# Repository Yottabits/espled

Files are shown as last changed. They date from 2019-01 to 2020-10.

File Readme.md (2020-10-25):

# ESP-LED - the ultimate LED-Strip-Controller-Board!

## What can it do?
* Controle RGB-LED strip (12V Mode)
* Controle RGBWW-LED strips (12V Mode)
* Controle WW LED-Strips (12V Mode)
* Controle WS2812 individually adressable LED Strips (5V Mode)
* Controle APA102 individually adressable LED Strips (5V Mode)
* Communicate over WiFi + MQTT
* Measure surrounding Temperature
* Sound-2-Light trough integrated Microphone

## How does it look like?
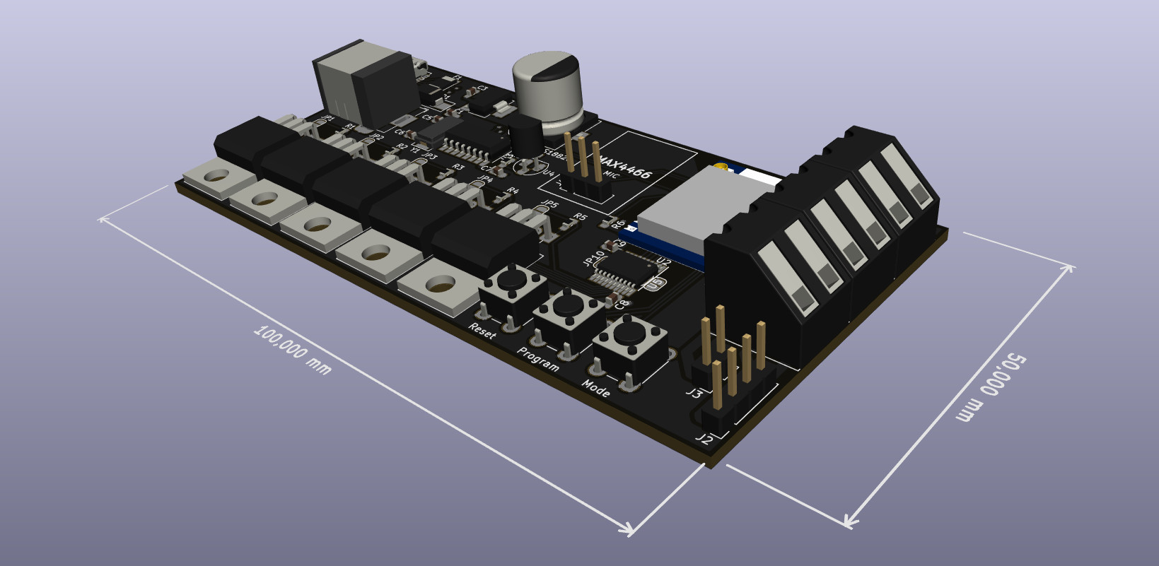
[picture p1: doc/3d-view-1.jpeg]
3D-View

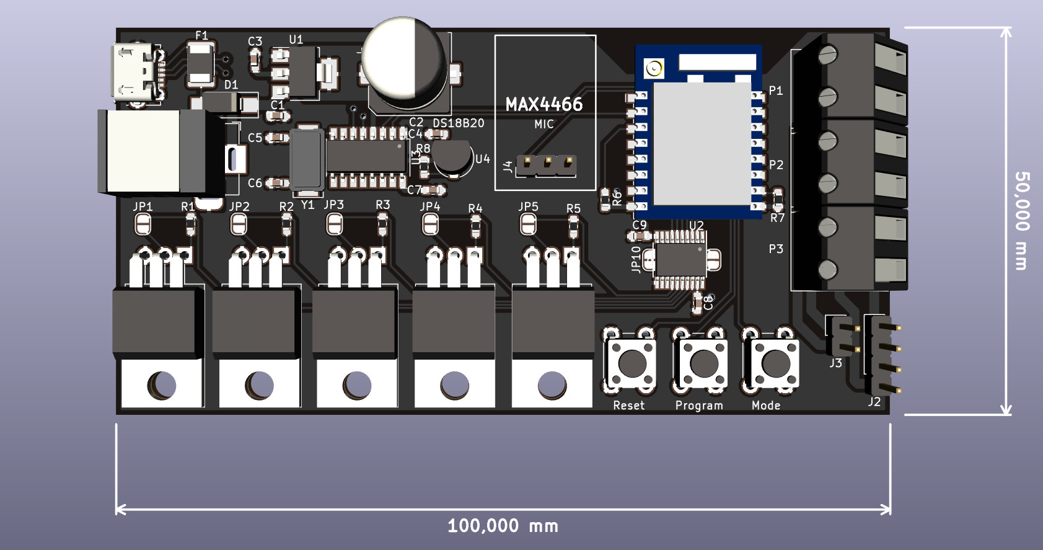
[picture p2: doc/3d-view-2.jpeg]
3D-View


## How does the Pinning look like?
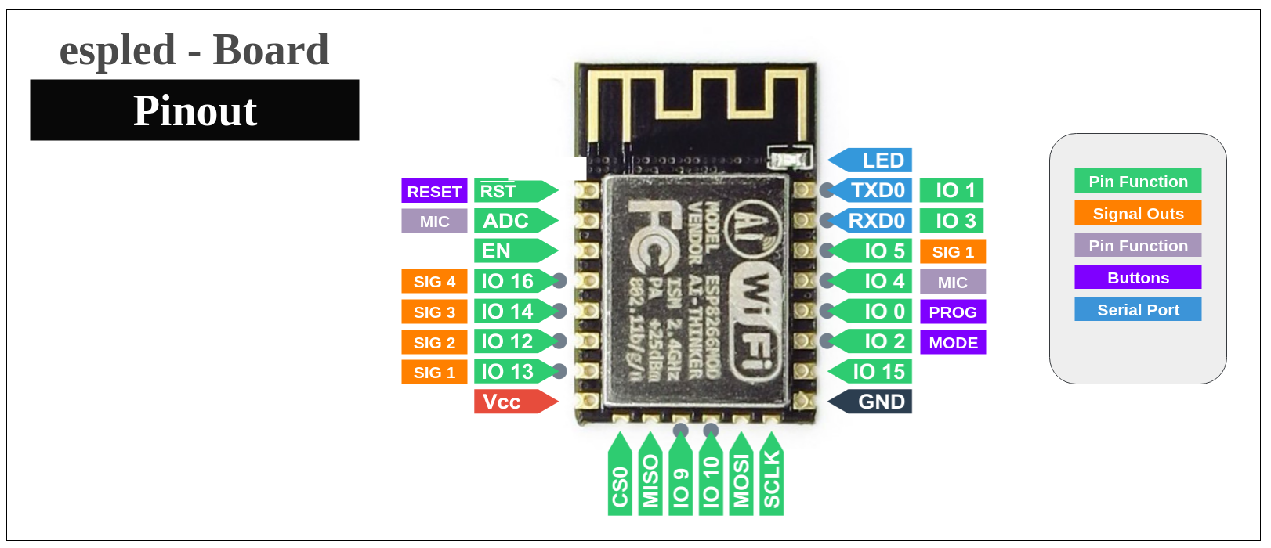
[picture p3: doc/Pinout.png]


## How to use it?

### How to use it in 12V Mode with RGBWW
Hardware:
* You only need to insert as many MOSFETS (IRLZ34N) as you want to controle Channels. Bridge the jumpers according to the table below

Software:
* Boot into configuration mode (see software README) and change the "LED Type" to "RGB", "RGBW" or "RGBWW" for 3, 4 or 5 active channels.

### How to use it in 5V Mode with WS2812
Hardware:
* Just bridge the Jumpers according to the table below.

Software:
* Boot into configuration mode (see software README) and change the "LED Type" to "WS2812".

### How to use it in 5V Mode with APA102
Hardware:
* Just bridge the Jumpers according to the table below.

Software:
* Boot into configuration mode (see software README) and change the "LED Type" to "APA102".

## What controle the Jumpers?
| Jumpernumber | Connects-Between | Function |
|---|---|---|
| 1 |Q1 Signal - Q1 Out| WS2812, APA102 |
| 2 |Q2 Signal - Q2 Out| APA102 |
| 3 |Q3 Signal - Q3 Out| |
| 4 |Q4 Signal - Q4 Out| |
| 5 |Q5 Signal - Q5 Out| |
| 6 | IO13 - Q1 | RGB, RGBW, RGBWW |
| 7 | IO12 - Q2 | RGB, RGBW, RGBWW |
| 8 | IO14 - Q3 | RGB, RGBW, RGBWW |
| 9 | IO16 - Q4 | RGBW, RGBWW |
| 10 | IO5 - Q5 | RGBWW |

## Which parts do I need?
See the Bill-Of-Materials file named ESPLED.csv in the hardware folder.

## Supported Modes
See Wiki (https://github.com/Yottabits/espled/wiki/Modes-Description)

## nice Projects with led animations for insperation
* GoodListOfAnimations for individually addressable strips: https://www.tweaking4all.com/hardware/arduino/arduino-all-ledstrip-effects-in-one/
* https://github.com/Aircoookie/WLED/wiki

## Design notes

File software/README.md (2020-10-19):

# Software manual
## Introduction

Although the ESPLED board is fully customizable, the default software should satisfy most users.

## Booting procedure
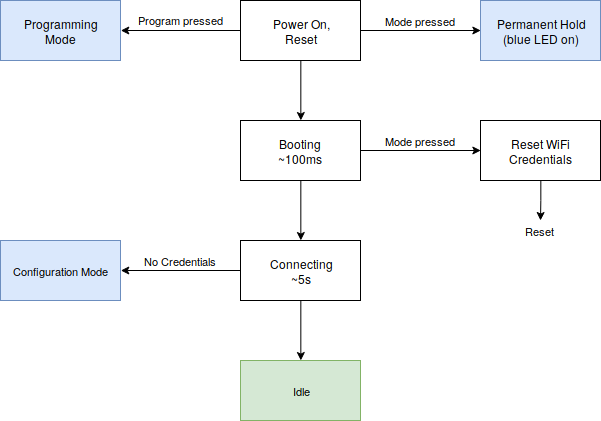
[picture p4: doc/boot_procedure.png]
boot


## Configuration
The configuration mode allows you to select your local WiFi network and the type of led strip you want to use.

To enter the configuration mode, perform the following tasks:
- Press and release the __reset__ button
- Press and hold the __mode__ button, the ESP Module should turn on its blue led permanently
- Hold the __mode__ button down until the led strip blinks blue once
- then the board is reset and should open up it's own wifi again

After sucessfully entering the configuration mode, use your smartphone or computer to connect to the wireless network called "ESPLED config" and follow the screen.

## Control LEDs
There are three different interfaces to connect to the controller.
*MQTT
*REST API
*On-Board-Button

### MQTT
The different functions of the controller are available under the following MQTT topic:

*/ESPLED/FF:FF:FF:FF:FF:FF* 
(replace with MAC of your device, visible in the setup routine)

The payload contais json in the following format:

```
{
  "mode": 0,
  "color": [
    1023,
    255,
    255,
    255,
    255
  ],
  "time": 1000
}
```

| Function | Topic | Values |
|---|---|---|
| Change Mode | mode | 0 to 200 |
| Color amplitudes | color[ R,G,B,(CW),(WW) ] | 10 bit integer |
| Timeframe in milliseconds(ex. fade time) | time | unsigned integer |
| Frequency in hertz | frequency | float |
| Relativ sensitivity | sensitivity | float (0.0 to 1.0) |
| Number of leds (mode specific) | length | unsigned integer |
| Select start led (mode specific) | position | unsigned integer |

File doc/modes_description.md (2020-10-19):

# Modes an mqtt 

## 0 fade2Color

### Description:
This is the most basic mode to change the strips color. You send the color a transition time. A transition time of 0 leads to an instant color jump.

### Parameters:
| Parameter | Effect | Unit | min. | man. |
|---|---|---|---|---|
| mode | changes Mode |  int |  0 |  0 |
| color | defines color in an Red-Green-Blue-WarmWhite-ColdWhite array | PWM  | 0 | 1023 |
| time | time until the end color is reached | milliseconds | 0 | 4294967295 ~ 49.7d |

### Example JSON:
``` JSON
{
  "mode":0,
  "color":[
      1023,
      1023,
      1023,
      1023,
      1023
  ],
  "time":1000
}
```

## 1 blinkColor

### Description:
This mode should be used for notifictaion. The Controller will store it's current state and blink in the selected color. You may select a number of blinks with the length parameter. 

### Parameters:
| Parameter | Effect | Unit | min. | man. |
|---|---|---|---|---|
| mode | changes Mode |  int |  1 |  1 |
| color | defines color in an Red-Green-Blue-WarmWhite-ColdWhite array | PWM  | 0 | 1023 |
| duration | duration of each max and min period | milliseconds | 0 | 4294967295 ~ 49.7d |
| length | number of blinks | int | 0 | ? |
| time | fadeTime from 0 to 1023| 0 | 4294967295 ~ 49.7d |

### Example JSON:
``` JSON
{
  "mode":1,
  "color":[
      1023,
      0,
      0,
      0,
      0
  ],
  "time":2000,
  "legth":3,
  "duration":1000
}
```

## 2 strobe
### Description:
This mode lights up the strip in the selected color and blinks it on/off in the selected frequency - no fading.

### Parameters:
| Parameter | Effect | Unit | min. | man. |
|---|---|---|---|---|
| mode | changes Mode |  t |  2 |  2 |
| color | defines color in an Red-Green-Blue-WarmWhite-ColdWhite array | PWM  | 0 | 1023 |
| frequency | changes the strobe frequency |  Hz |  1 |  60 |

### Example JSON:
``` JSON
{
  "mode":2,
  "color":[
      800,
      120,
      1023,
      0,
      0
  ],
  "frequency":20
}
```

## 3 sound2Light

## 4 breathe
### Description:
This mode realizes a breathing function. This means the whole strip gets dimmed up and down. You can add some randomness to that through timeVariance and maxBrightnessVariance.

### Parameters:
| Parameter | Effect | Unit | min. | man. |
|---|---|---|---|---|
| mode | changes Mode |  t |  4 |  4 |
| color | defines color in an Red-Green-Blue-WarmWhite-ColdWhite array | PWM  | 0 | 1023 |
| time | Period of whole "breath" (effected by time Variance) | milliseconds | 0 | 4294967295 ~ 49.7d |
| minBrightnes | minimum Brightness | PWM | 0 | 1023 |
| maxBrightnes | maximum Brightness (effected by maxBrightnesVariance) | PWM | 0 | 1023 |
| timeVariance | if set each breath a random amount of ms within the Interval [-timeVariance <> +timeVariance] gets added to the breath time| millisceonds | 0 | 4294967295 ~ 49.7d  |
| maxBrightnesVariance | if set each breath a random amount of brightnes within the Interval [-maxBrightnesVariance <> +maxBrightnesVariance] gets added to maxBrightnes| PWM | 0 | 1023 |

### Example JSON:
``` JSON
{
  "mode":4,
  "color":[
      1023,
      0,
      0,
      0,
      0
  ],
  "time":6000,
  "minBrightnes":0,
  "maxBrightnes":1023,
  "timeVariance":3000,
  "maxBrightnesVariance":500
}
```

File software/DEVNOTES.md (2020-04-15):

# Software development notes and ideas
## User Interface
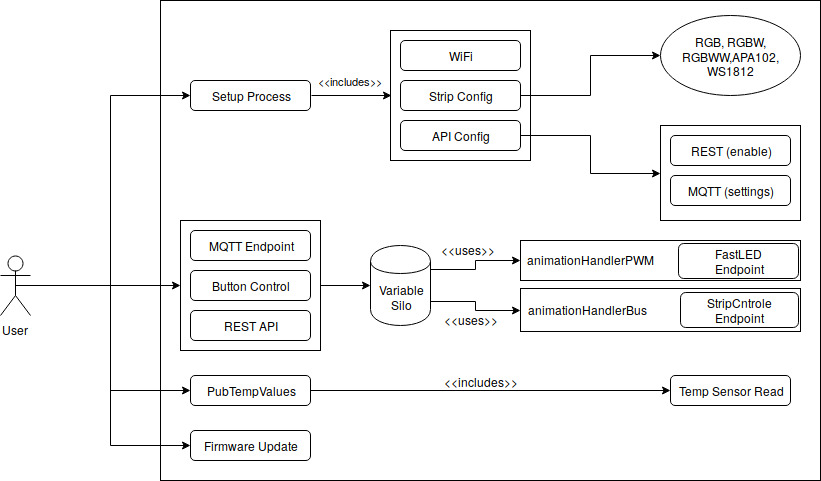
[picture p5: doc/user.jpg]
User Interface


## Class __StripControle__
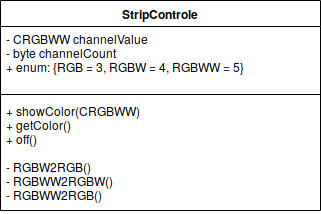
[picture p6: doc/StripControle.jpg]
StripControle


## Solution to the double class problem
```cpp
//Setup
FastLed* fastLed;
StripControle* stripControle;

//Init
if(ledChipsetBased)
{
  fastLed = new FastLed(ledArray);
}
else
{
  stripControle = new StripControle;
}
```

## AnnimationHandlers
* Both Classes AnimationHandlerPWM and AnimationHandlerBus have a method handle that is periodically called
* This handler then periodically calls functions defining the modes (distinct for bus and non Bus Stips)
* Example: animationHandlerBus.fade(Color,time)
* All current state Informations for timing-sensitive Modes is stored as static variables within their periodically called functions
* For Timing-Measurements we use the millis-command
* For Accessing the LEDs both AnimationHandlers hold attributes of the Type FastLedEndpoint and StripControleEndpoint which do the lower Level Stuff
* All Modes implemented in the AnimationHandlerPWM should also be Implemented in the AnimationHandlerBus

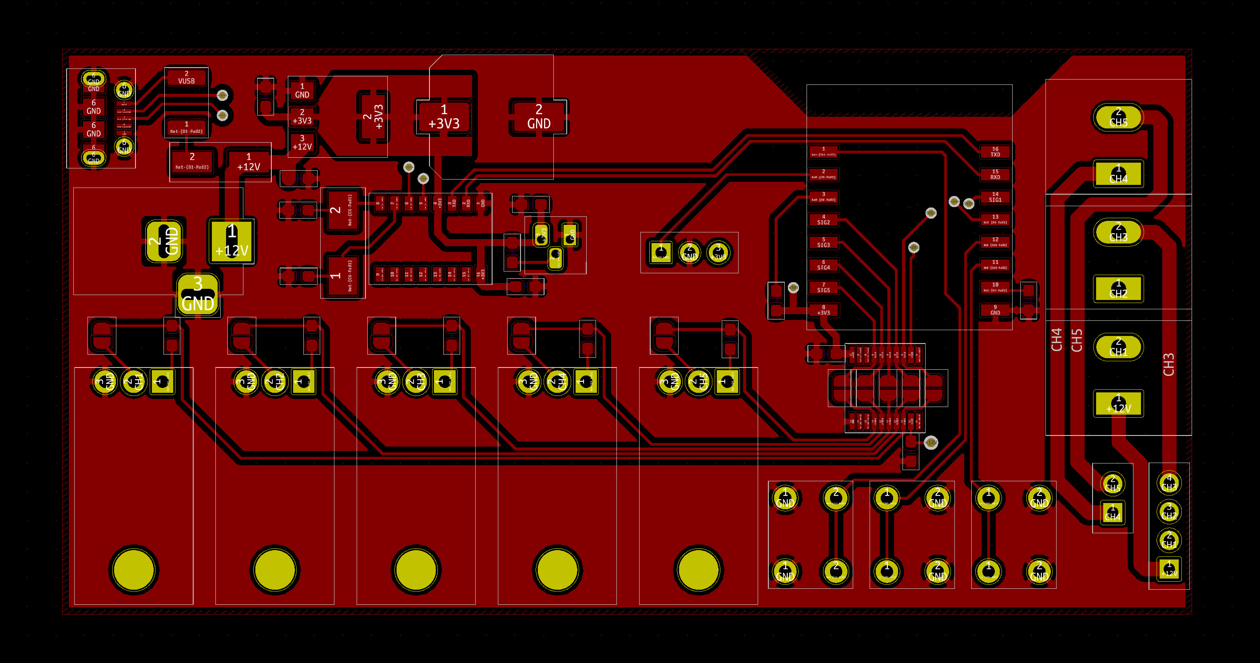
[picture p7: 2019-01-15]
doc/top_layer.jpg

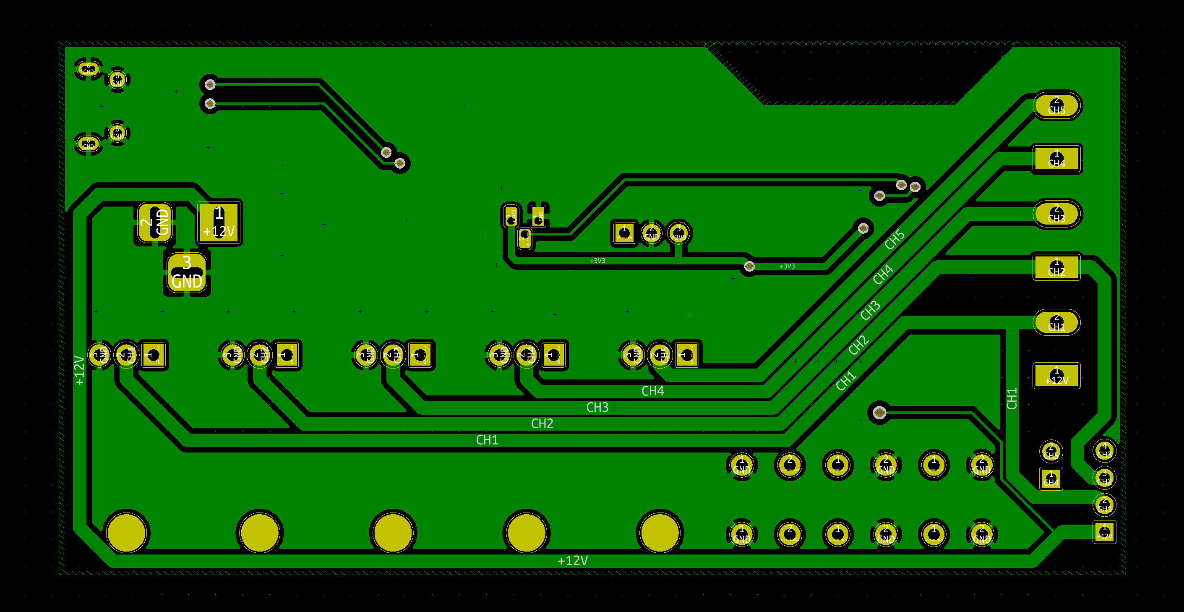
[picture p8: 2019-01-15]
doc/bottom_layer.jpg

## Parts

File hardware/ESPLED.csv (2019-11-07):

Reference | Value | Footprint | Datasheet | SKU | MPN
U2 | ESP-07v2 | RF_Module:ESP-07
C2 | 1000uF | Capacitor_SMD:CP_Elec_10x10.5
C3 | 1uF | Capacitor_SMD:C_0603_1608Metric_Pad1.05x0.95mm_HandSolder
CON1 | BARREL_JACK | Connector_BarrelJack:BarrelJack_Horizontal
Q1 | IRLZ34N | Package_TO_SOT_THT:TO-220-3_Horizontal_TabDown
Q2 | IRLZ34N | Package_TO_SOT_THT:TO-220-3_Horizontal_TabDown
Q3 | IRLZ34N | Package_TO_SOT_THT:TO-220-3_Horizontal_TabDown
R1 | 100 | Resistor_SMD:R_0603_1608Metric_Pad1.05x0.95mm_HandSolder
R2 | 100 | Resistor_SMD:R_0603_1608Metric_Pad1.05x0.95mm_HandSolder
R3 | 100 | Resistor_SMD:R_0603_1608Metric_Pad1.05x0.95mm_HandSolder
R6 | 10k | Resistor_SMD:R_0603_1608Metric_Pad1.05x0.95mm_HandSolder
R7 | 10k | Resistor_SMD:R_0603_1608Metric_Pad1.05x0.95mm_HandSolder
SW1 | Reset | Button_Switch_THT:SW_PUSH_6mm
P3 | LED_CON_SCREW | TerminalBlock:TerminalBlock_Altech_AK300-2_P5.00mm |  | 320110028
P1 | LED_CON_SCREW | TerminalBlock:TerminalBlock_Altech_AK300-2_P5.00mm |  | 320110028
C4 | 100nF | Capacitor_SMD:C_0603_1608Metric_Pad1.05x0.95mm_HandSolder
U3 | INTERFACE-CH340G | Package_SO:SOP-16_4.4x10.4mm_P1.27mm |  | 310070026 | CH340T
J1 | USB_B_Micro | Connector_USB:USB_Micro-B_Molex-105017-0001
Y1 | Crystal | Crystal:Crystal_SMD_0603-2Pin_6.0x3.5mm_HandSoldering
SW3 | Mode | Button_Switch_THT:SW_PUSH_6mm
C5 | 22p | Capacitor_SMD:C_0603_1608Metric_Pad1.05x0.95mm_HandSolder
C6 | 22p | Capacitor_SMD:C_0603_1608Metric_Pad1.05x0.95mm_HandSolder
C7 | 100n | Capacitor_SMD:C_0603_1608Metric_Pad1.05x0.95mm_HandSolder
D1 | 1N5817 | Diode_SMD:D_SMA_Handsoldering
J4 | MIC | Connector_PinHeader_2.54mm:PinHeader_1x03_P2.54mm_Vertical
J2 | LED_CON_RGB | Connector_PinHeader_2.54mm:PinHeader_1x04_P2.54mm_Vertical
Q4 | IRLZ34N | Package_TO_SOT_THT:TO-220-3_Horizontal_TabDown
R4 | 100 | Resistor_SMD:R_0603_1608Metric_Pad1.05x0.95mm_HandSolder
Q5 | IRLZ34N | Package_TO_SOT_THT:TO-220-3_Horizontal_TabDown
R5 | 100 | Resistor_SMD:R_0603_1608Metric_Pad1.05x0.95mm_HandSolder
P2 | LED_CON_SCREW | TerminalBlock:TerminalBlock_Altech_AK300-2_P5.00mm |  | 320110028
U1 | AMS1117-3.3 | Package_TO_SOT_SMD:SOT-223-3_TabPin2
F1 | Polyfuse | Fuse:Fuse_1812_4532Metric_Pad1.30x3.40mm_HandSolder
JP1 | GPIO LINK | Jumper:SolderJumper-2_P1.3mm_Open_RoundedPad1.0x1.5mm
JP2 | GPIO LINK | Jumper:SolderJumper-2_P1.3mm_Open_RoundedPad1.0x1.5mm
JP3 | GPIO LINK | Jumper:SolderJumper-2_P1.3mm_Open_RoundedPad1.0x1.5mm
JP4 | GPIO LINK | Jumper:SolderJumper-2_P1.3mm_Open_RoundedPad1.0x1.5mm
JP5 | GPIO LINK | Jumper:SolderJumper-2_P1.3mm_Open_RoundedPad1.0x1.5mm
U4 | DS18B20 | Package_TO_SOT_THT:TO-92_HandSolder
R8 | 4.7K | Resistor_SMD:R_0603_1608Metric_Pad1.05x0.95mm_HandSolder
SW2 | Program | Button_Switch_THT:SW_PUSH_6mm
C1 | 1uF | Capacitor_SMD:C_0603_1608Metric_Pad1.05x0.95mm_HandSolder
J3 | LED_CON_WW | Connector_PinHeader_2.54mm:PinHeader_1x02_P2.54mm_Vertical | ~
U5 | TXS0108EPW | Package_SO:TSSOP-20_4.4x6.5mm_P0.65mm | www.ti.com/lit/ds/symlink/txs0108e.pdf
JP6 | GPIO LINK | Jumper:SolderJumper-2_P1.3mm_Open_RoundedPad1.0x1.5mm | ~
JP7 | GPIO LINK | Jumper:SolderJumper-2_P1.3mm_Open_RoundedPad1.0x1.5mm | ~
JP8 | GPIO LINK | Jumper:SolderJumper-2_P1.3mm_Open_RoundedPad1.0x1.5mm | ~
JP9 | GPIO LINK | Jumper:SolderJumper-2_P1.3mm_Open_RoundedPad1.0x1.5mm | ~
JP10 | GPIO LINK | Jumper:SolderJumper-2_P1.3mm_Open_RoundedPad1.0x1.5mm | ~
C9 | 100nF | Capacitor_SMD:C_0603_1608Metric_Pad1.05x0.95mm_HandSolder | ~
C8 | 100nF | Capacitor_SMD:C_0603_1608Metric_Pad1.05x0.95mm_HandSolder | ~

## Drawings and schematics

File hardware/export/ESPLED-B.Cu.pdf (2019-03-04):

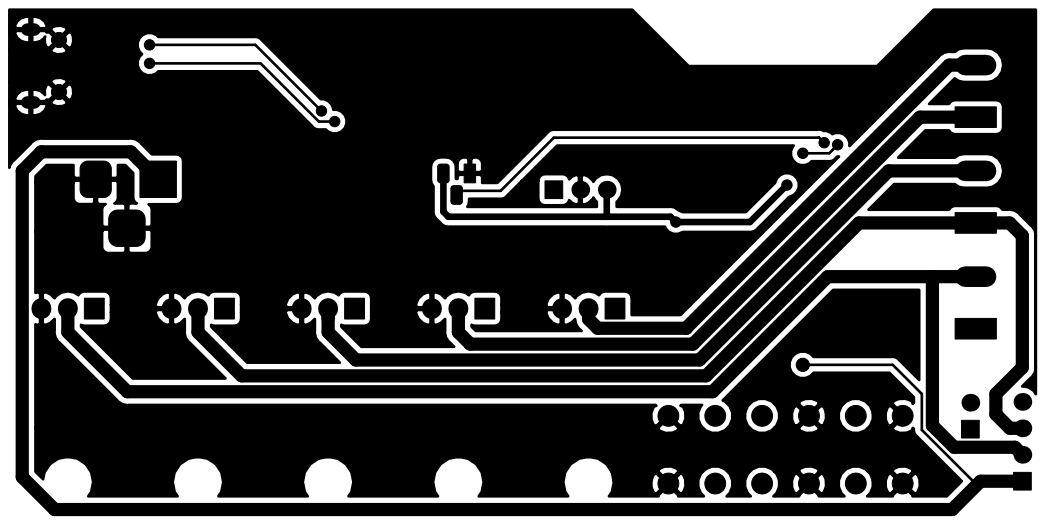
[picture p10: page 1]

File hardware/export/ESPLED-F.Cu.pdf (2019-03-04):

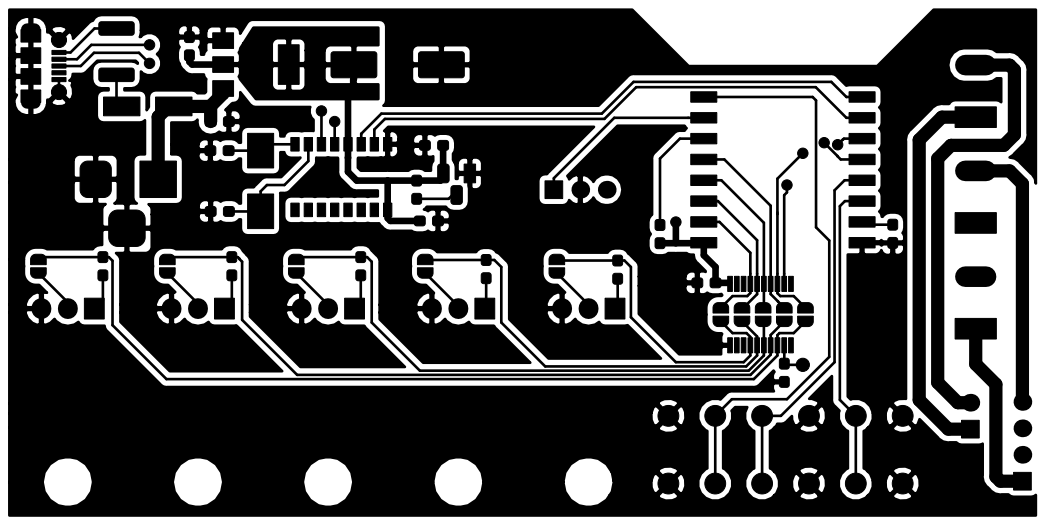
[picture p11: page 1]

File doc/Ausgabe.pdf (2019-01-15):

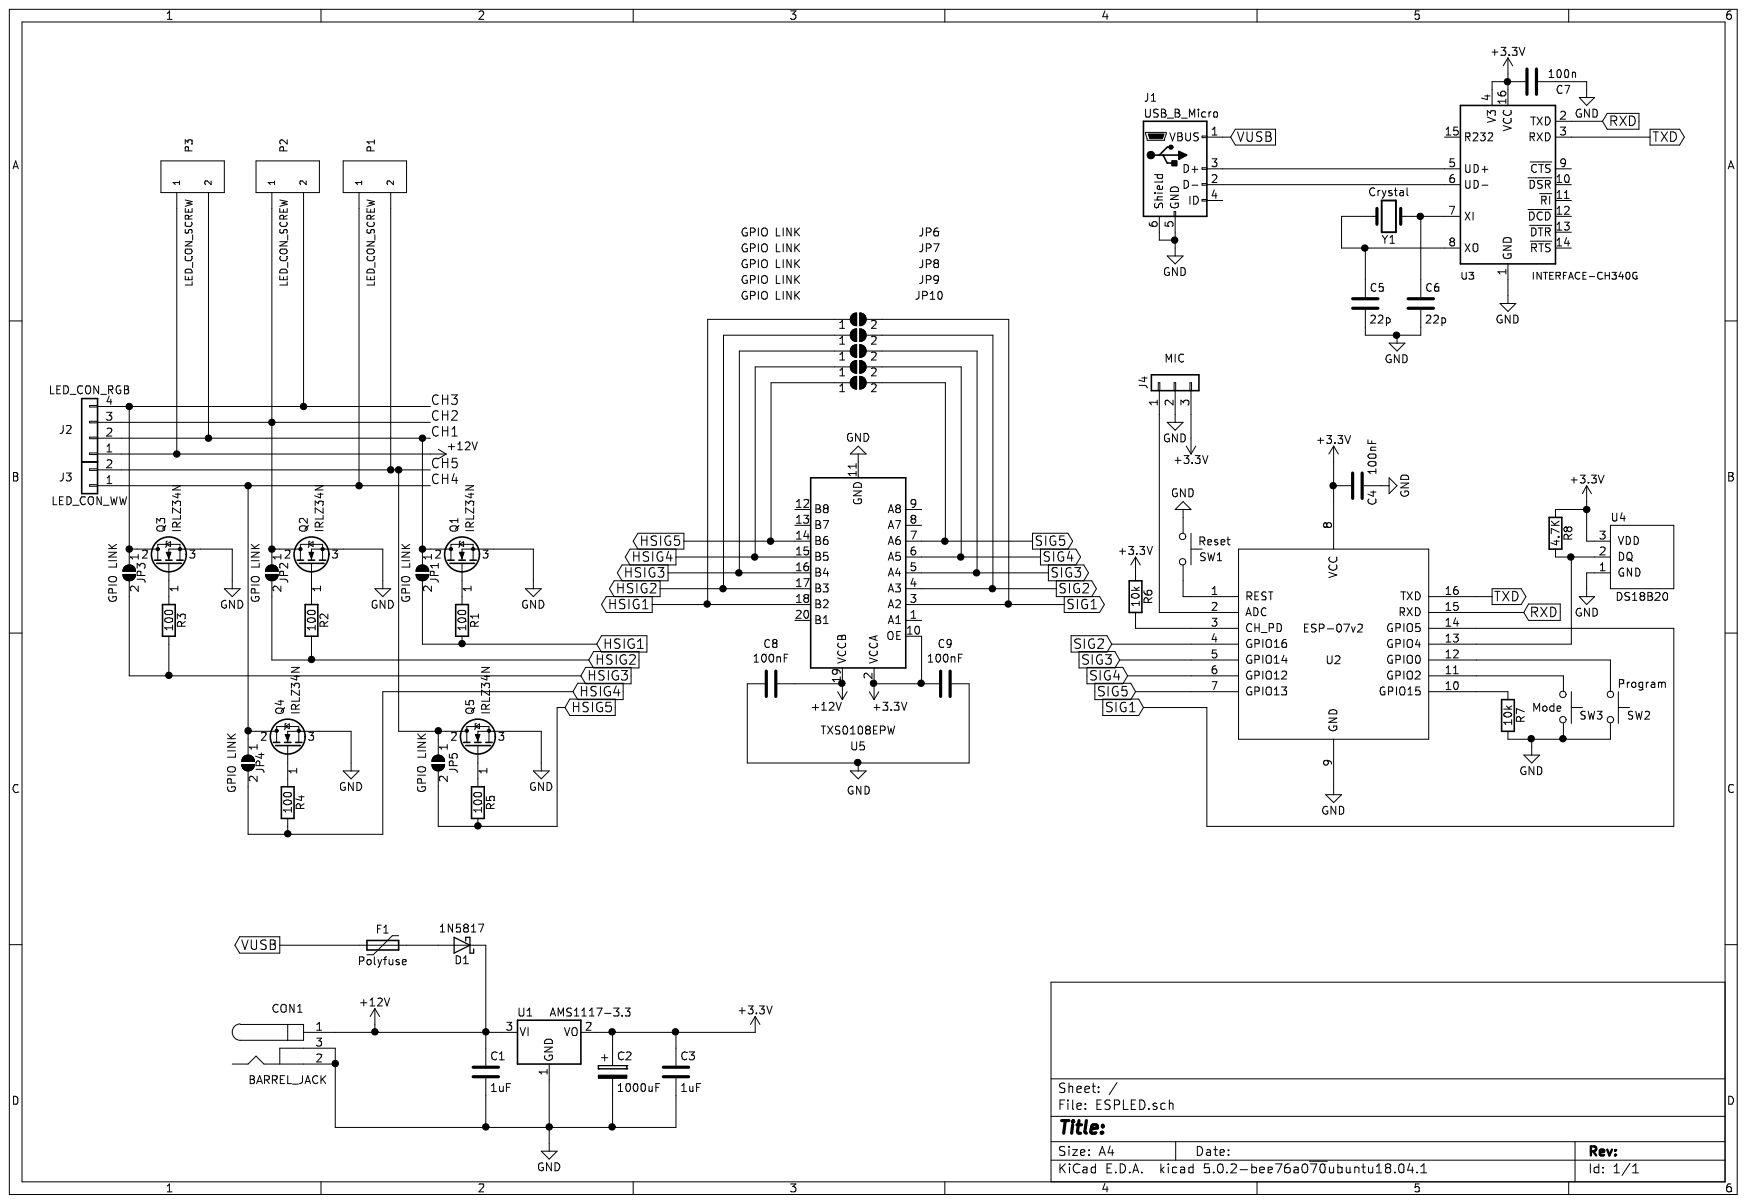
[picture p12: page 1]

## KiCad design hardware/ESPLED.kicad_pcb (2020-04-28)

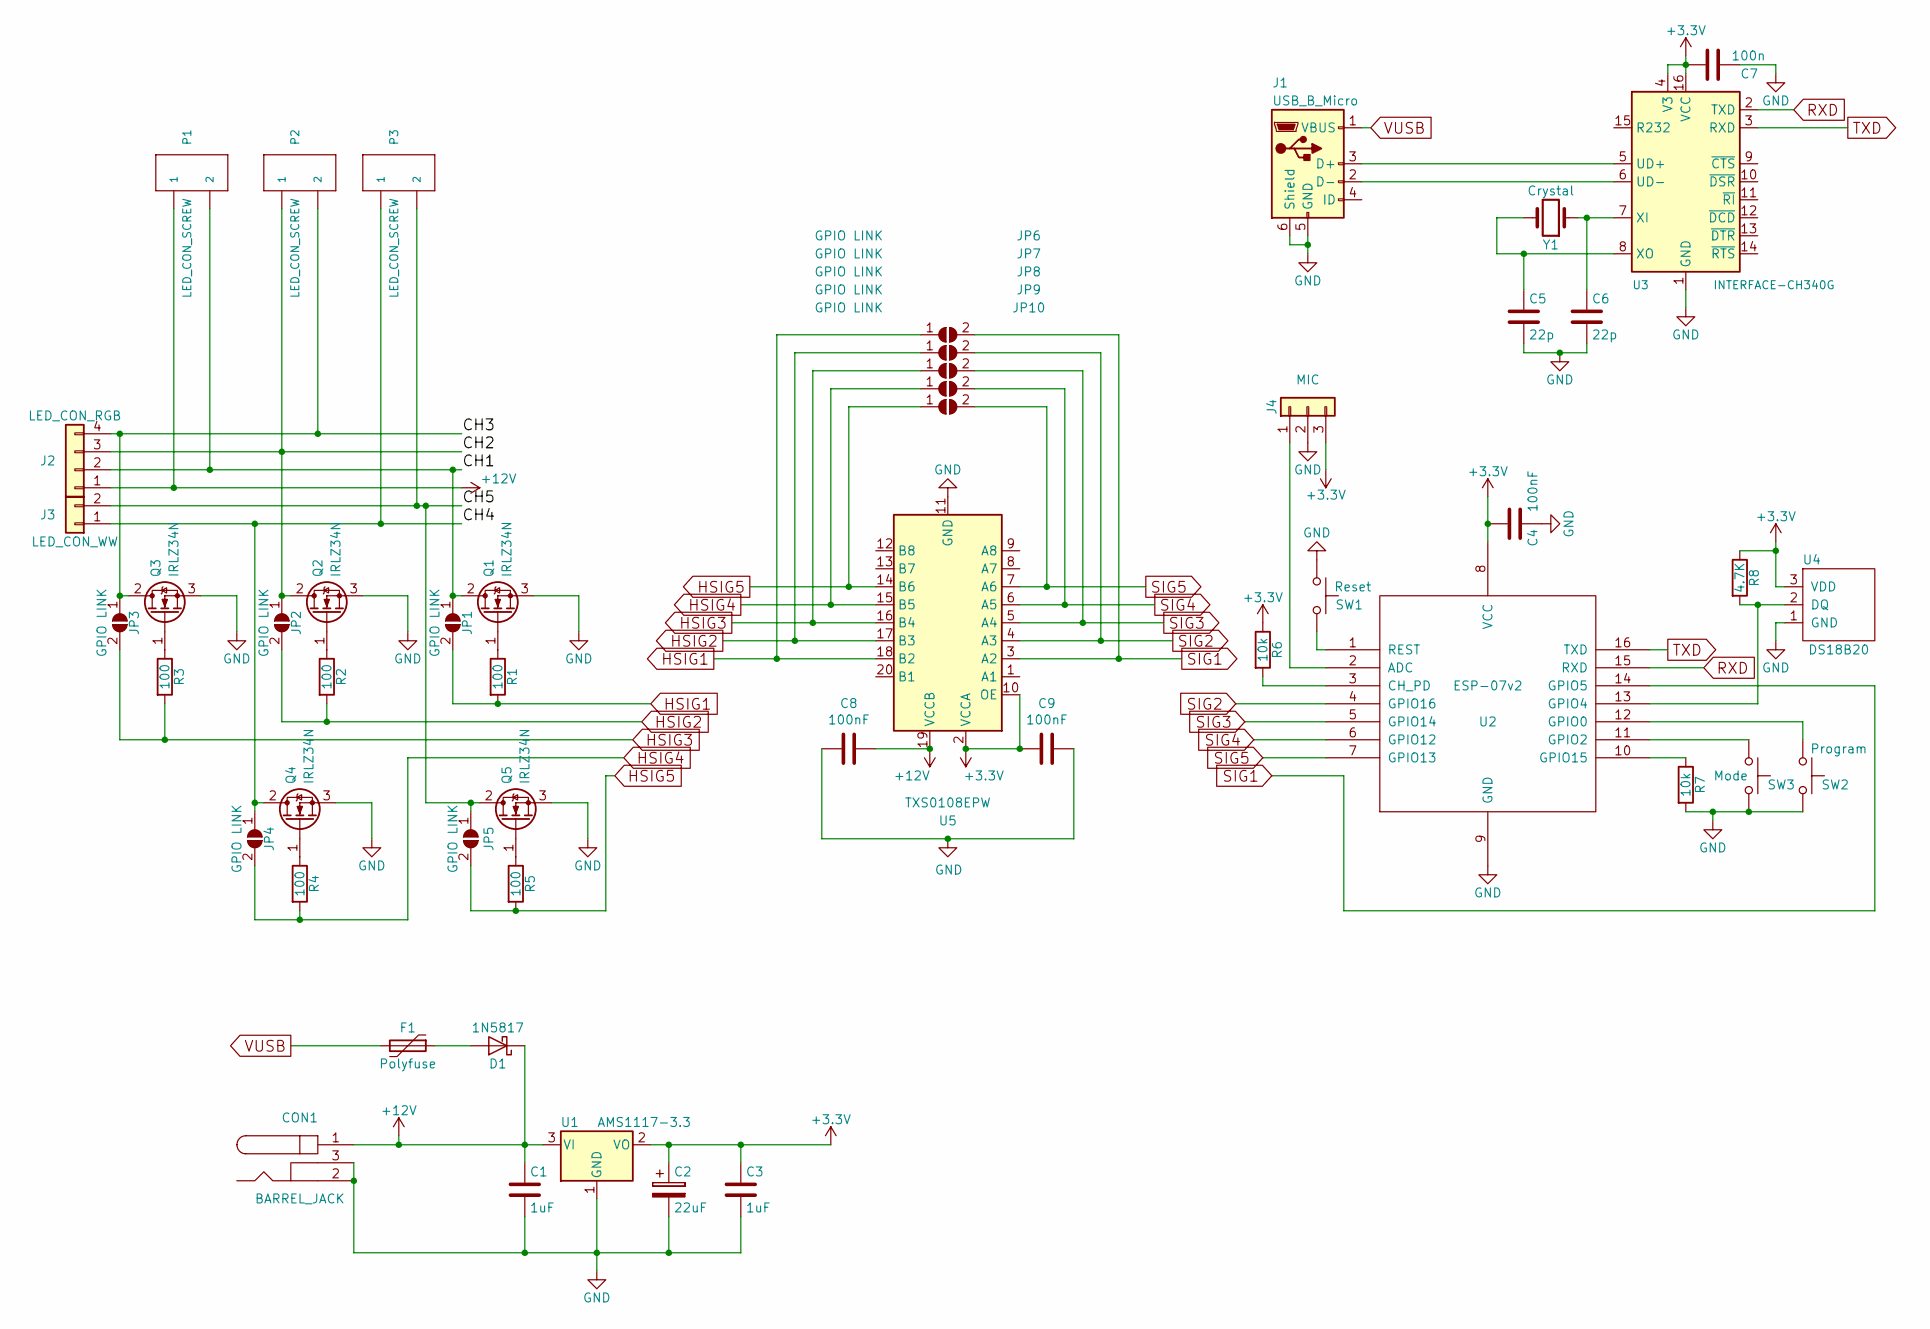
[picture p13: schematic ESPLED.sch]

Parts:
C1, C3: 1uF; C_0603_1608Metric_Pad1.05x0.95mm_HandSolder
C2: 22uF; CP_Elec_10x10.5
C4, C8, C9: 100nF; C_0603_1608Metric_Pad1.05x0.95mm_HandSolder
C5, C6: 22p; C_0603_1608Metric_Pad1.05x0.95mm_HandSolder
C7: 100n; C_0603_1608Metric_Pad1.05x0.95mm_HandSolder
CON1: BARREL_JACK; BarrelJack_Horizontal
D1: 1N5817; D_SMA_Handsoldering
F1: Polyfuse; Fuse_1812_4532Metric_Pad1.30x3.40mm_HandSolder
J1: USB_B_Micro; USB_Micro-B_Molex-105017-0001
J2: LED_CON_RGB; PinHeader_1x04_P2.54mm_Vertical
J3: LED_CON_WW; PinHeader_1x02_P2.54mm_Vertical
J4: MIC; PinHeader_1x03_P2.54mm_Vertical
JP1, JP2, JP3, JP4, JP5, JP6, JP7, JP8, JP9, JP10: GPIO LINK; SolderJumper-2_P1.3mm_Open_RoundedPad1.0x1.5mm
P1, P2, P3: LED_CON_SCREW; TerminalBlock_Altech_AK300-2_P5.00mm
Q1, Q2, Q3, Q4, Q5: IRLZ34N; TO-220-3_Horizontal_TabDown
R1, R2, R3, R4, R5: 100; R_0603_1608Metric_Pad1.05x0.95mm_HandSolder
R6, R7: 10k; R_0603_1608Metric_Pad1.05x0.95mm_HandSolder
R8: 4.7K; R_0603_1608Metric_Pad1.05x0.95mm_HandSolder
SW1: Reset; SW_PUSH_6mm
SW2: Program; SW_PUSH_6mm
SW3: Mode; SW_PUSH_6mm
U1: AMS1117-3.3; SOT-223-3_TabPin2
U2: ESP-07v2; ESP-07
U3: INTERFACE-CH340G; SOP-16_4.4x10.4mm_P1.27mm; MPN CH340T
U4: DS18B20; TO-92_HandSolder
U5: TXS0108EPW; TSSOP-20_4.4x6.5mm_P0.65mm
Y1: Crystal; Crystal_SMD_0603-2Pin_6.0x3.5mm_HandSoldering

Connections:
+3V3: C2.1, C3.1, C4.2, C7.2, C9.2, J4.3, R6.1, R8.1, U1.2 (VO), U2.8 (VCC), U3.4 (V3), U3.16 (VCC), U4.3 (VDD), U5.2 (VCCA), U5.10 (OE)
+12V: C1.1, C8.1, CON1.1, D1.1 (K), J2.1, P1.1, U1.3 (VI), U5.19 (VCCB)
/CH1: J2.2, JP1.1 (A), P1.2, Q1.2 (D)
/CH2: J2.3, JP2.1 (A), P2.1, Q2.2 (D)
/CH3: J2.4, JP3.1 (A), P2.2, Q3.2 (D)
/CH4: J3.1, JP4.1 (A), P3.1, Q4.2 (D)
/CH5: J3.2, JP5.1 (A), P3.2, Q5.2 (D)
GND: C1.2, C2.2, C3.2, C4.1, C5.2, C6.2, C7.1, C8.2, C9.1, CON1.2, CON1.3, J1.5 (GND), J1.6 (Shield), J4.2, Q1.3 (S), Q2.3 (S), Q3.3 (S), Q4.3 (S), Q5.3 (S), R7.2, SW1.1, SW2.2, SW3.2, U1.1 (GND), U2.9 (GND), U3.1 (GND), U4.1 (GND), U5.11 (GND)
HSIG1: JP1.2 (B), JP6.1 (A), R1.2, U5.18 (B2)
HSIG2: JP2.2 (B), JP7.1 (A), R2.2, U5.17 (B3)
HSIG3: JP3.2 (B), JP8.1 (A), R3.2, U5.16 (B4)
HSIG4: JP4.2 (B), JP9.1 (A), R4.2, U5.15 (B5)
HSIG5: JP5.2 (B), JP10.1 (A), R5.2, U5.14 (B6)
unnamed: C5.1, U3.8 (XO), Y1.2
unnamed: C6.1, U3.7 (XI), Y1.1
unnamed: D1.2 (A), F1.1
unnamed: J1.2 (D-), U3.6 (UD-)
unnamed: J1.3 (D+), U3.5 (UD+)
unnamed: J4.1, U2.2 (ADC)
unnamed: Q1.1 (G), R1.1
unnamed: Q2.1 (G), R2.1
unnamed: Q3.1 (G), R3.1
unnamed: Q4.1 (G), R4.1
unnamed: Q5.1 (G), R5.1
unnamed: R6.2, U2.3 (CH_PD)
unnamed: R7.1, U2.10 (GPIO15)
unnamed: R8.2, U2.13 (GPIO4), U4.2 (DQ)
unnamed: SW1.2, U2.1 (REST)
unnamed: SW2.1, U2.12 (GPIO0)
unnamed: SW3.1, U2.11 (GPIO2)
RXD: U2.15 (RXD), U3.2 (TXD)
SIG1: JP6.2 (B), U2.14 (GPIO5), U5.3 (A2)
SIG2: JP7.2 (B), U2.4 (GPIO16), U5.4 (A3)
SIG3: JP8.2 (B), U2.5 (GPIO14), U5.5 (A4)
SIG4: JP9.2 (B), U2.6 (GPIO12), U5.6 (A5)
SIG5: JP10.2 (B), U2.7 (GPIO13), U5.7 (A6)
TXD: U2.16 (TXD), U3.3 (RXD)
VUSB: F1.2, J1.1 (VBUS)

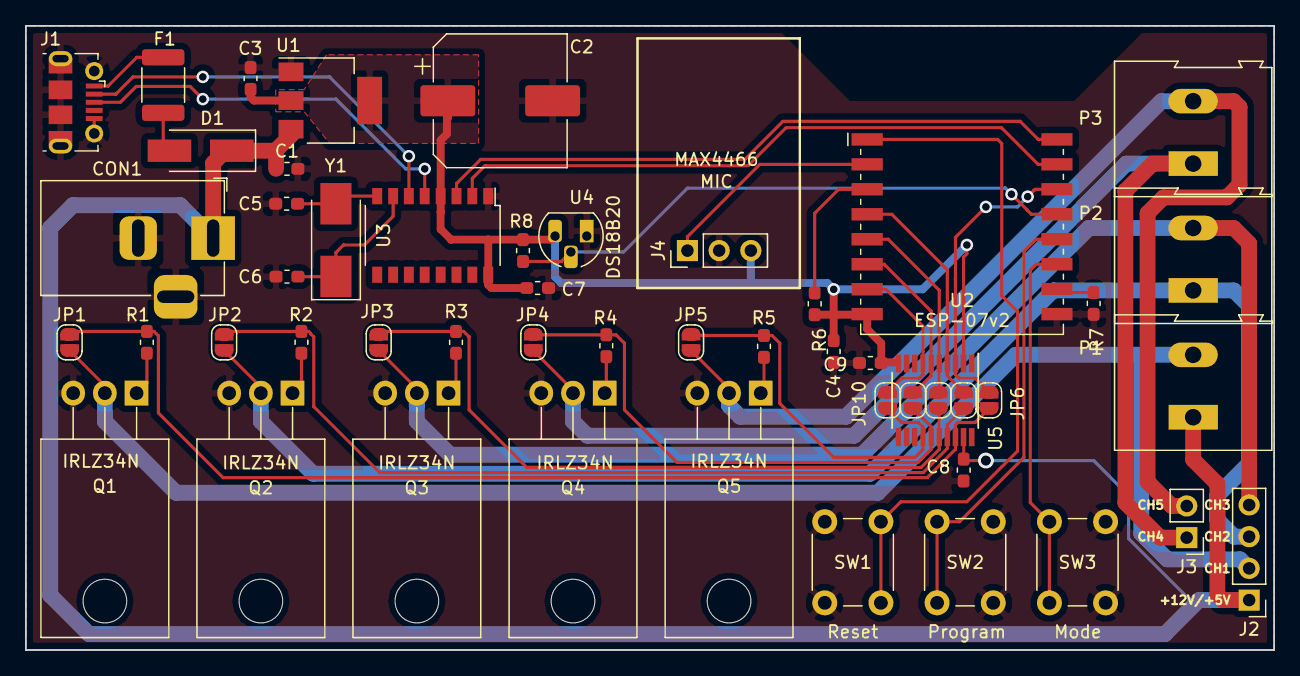
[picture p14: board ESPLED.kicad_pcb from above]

Board: 2 copper layers, 100.0 x 50.0 mm, 51 parts (0 on the bottom side), 38 nets.

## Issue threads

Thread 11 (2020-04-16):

Fix swapped capacitor label near microcontroller

aewatt95, 2020-04-16:

Closed 2020-04-28.

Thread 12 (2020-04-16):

Change label order of connector P1 P2 P3

aewatt95, 2020-04-16:

aewatt95, 2020-04-19:
Almost ready to close this issue. I'm going to combine the fix with issue #11.

Closed 2020-04-28.

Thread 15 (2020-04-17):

Reorganize Classes/Methods for modes in Annimation Handlers

domiko96, 2020-04-17:
- Modes access directly the var Silo and Attributes of BusHandler Classes
- handle() takes care of the 60Hz update rate
- Modes return ColorValue if called
- handle() writes this value to strip (once or multiple times in case of Bus - for each led)
- maybe use inheritence for BusHandlers
- Modes are Methods of BusHandler SuperClass

Closed 2020-04-17.

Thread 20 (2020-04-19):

Change microUSB Footprint on Board

domiko96, 2020-04-19:

aewatt95, 2020-04-28:
The footprint is alright. We just used SMD only parts instead of the through hole parts we designed the board for.

Closed 2020-04-28.

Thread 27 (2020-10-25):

Sensor support configurable and merge DHT11 to Master

domiko96, 2020-10-25:
I prefer a WifiManager Setting between {no_sensor, DHT11, DS18B20} so the user can specify his/her configuration.
Also Sensor related code should be moved to seperate file out of main. (--> Sensor lib and some code in initFunctions)

If solved I propose to merge DHT11 to Master.

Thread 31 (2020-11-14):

Add LowLevel MQTT Endpoint

domiko96, 2020-11-14:
Idea:
Add a lowlevel dircet access MQTT Topic per espled board, where one could send raw bytes for individual leds (not as json). So we can send a full strip state from a Python/Go Application.
We definitely should evaluate the performance and latency along with qos capabilities of mqtt.

To ensure high performance:
* Write directly to Fastled buffer (or PWM Outputs) without copying
* Use raw bytes insead of json -> no parsing and buffer needs

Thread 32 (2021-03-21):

Ideas for new HW Revision

domiko96, 2021-03-21:
- Use Step down instead of Voltage Regulator
   https://www.bastelgarage.ch/s09-3-3v-step-up-down-converter-3-15v-nach-3-3v-600ma
   Works for 5V and 12V strips
- Place 100nF Capacitor correct

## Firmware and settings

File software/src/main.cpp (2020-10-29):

//--Includes--------------------------------------------------------------------
#include <initFunctions.h>
//--Includes--------------------------------------------------------------------


void debugFkt(String message, LogLevel LevelOfMessage){
  // Function which handles the debugging
  // Prints messages depending on log_level to MQTT and Serial

  if(LOGLEVEL <= LevelOfMessage){
    //Add Level to message
    switch (LevelOfMessage)
    {
    case VERBOSE:
      message = "[VERBOSE]:"+message;
      break;
    case DEBUG:
      message = "[DEBUG]:"+message;
      break;
    case INFO:
      message = "[INFO]:"+message;
      break;
    case WARNING:
      message = "[WARNING]:"+message;
      break;
    case ERROR:
      message = "[ERROR]:"+message;
      break;
    default:
      break;
    }
    message += "";

    static unsigned int lastMQTTPublished = 0;
    //if(millis() > lastMQTTPublished + 100F){
      lastMQTTPublished = millis();
      if(client.connected())
        client.publish(debugTopic, message.c_str());
      Serial.println(message);
    //}

  }
}


void firmmareReset(){
  delay(2000);
  if(digitalRead(pinM) == LOW){
    wifiManager.resetSettings();
    SPIFFS.format();
    digitalWrite(pinB, HIGH);
    delay(500);
    digitalWrite(pinB, LOW);
  }
}


void runAnimationHandler(){
  if(*type < 6){
    pwmHandler->handle();
  }
  else{
    //TODO
    busHandler->handle();
  }
}


void setup(){
  initPins();

  firmmareReset();
  Serial.begin(115200);
  delay(50);
  debugFkt("Booting", INFO);

  initFS();
  initWifi();
  initMQTT();
  initOta();
  initStrip();

  debugFkt("Ready", INFO);
  debugFkt("IP address: " + WiFi.localIP().toString(), INFO);
  //simpleStrip->showColor(CRGBWW{0,1023,0,1023,0});
  delay(500);
  //simpleStrip->showColor(CRGBWW{0,0,0,0,0});
}

void handleReconnect(){
  if(!client.connected()) {
      initMQTT();
    }
}

unsigned int cycleCount = 0;
unsigned int freeHeap = 0;

void loop() {
  cycleCount = ESP.getCycleCount();
  //OTA Handler
  ArduinoOTA.handle();

  //Run PWM Handler handle
  runAnimationHandler();

  //Run Microphone Handler handle
  micHandler->handleMic();

  //Reconnect MQTT if conenction is lost
  handleReconnect();

  //Handle MQTT routine
  client.loop();



  //Debug system resources
  if(!(millis() % 500)){
    debugFkt(
      "cycleCount: " + String(ESP.getCycleCount() - cycleCount) +
      " LoopTime: " + String((ESP.getCycleCount() - cycleCount) / 80000.0) + "ms" +
      " freeHeap: " + String(ESP.getFreeHeap() / 1000.0) + "kB"
    , VERBOSE);
  }
}

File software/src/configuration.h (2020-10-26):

#ifndef CONFIGURATION_H
#define CONFIGURATION_H


#include <TypeDefinitions.h>
#include <FastLED.h>

const unsigned int pwmFreq = 2000;

//default values in configruation interface

char mqtt_server[40];
char mqtt_port[6] = "1883";
char strip_type[8] = "RGB";
char strip_length[5] = "100";
char mqtt_ssl[3] = "no";
char mqtt_username[40] = "esp";
char mqtt_password[40] = "supersecurepassword";

char mainTopic[80] = "/ESPLED/";
char debugTopic[80];

//Fingerprint of odroid
const char* fingerprint = "A6 AE 85 65 63 DD D8 7C 70 F7 92 73 DE 8F 18 2B 9F DA 0A 76";
const LogLevel LOGLEVEL = DEBUG;

#endif

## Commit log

2018-11-24 Init: Version 2: external programmer, mosfet pinout fix
    [ESPLED.csv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]
2018-11-24 All coponents set
    [ESPLED.kicad_pcb, ESPLED.sch]
2018-11-24 Added power suply switching circuit, cleaned up
    [ESPLED.csv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]
2018-11-24 First PCB Layout generated. TODO: Screw terminal fix
    [ESPLED.dsn, ESPLED.kicad_pcb]
2018-11-26 Added caps for crystal
    [ESPLED.kicad_pcb, ESPLED.sch]
2018-11-26 Schematic done. Next: Fottprint research
    [ESPLED.sch]
2019-01-07 Footprint research done, layout more or less gelayoutet
    [ESPLED-2018-11-27-00-14-09.sch, ESPLED.kicad_pcb]
2019-01-07 Ongoin reordering. Will probably
    [ESPLED.kicad_pcb, ESPLED.sch]
2019-01-08 Routing done! Next step: verification
    [ESPLED.kicad_pcb, ESPLED.sch]
2019-01-14 layout finished. Adding logic level converter
    [ESPLED.kicad_pcb, ESPLED.sch]
2019-01-14 Go to gitlab
    [_saved_ESPLED.sch]
2019-01-14 Logic Level Converter added. Schematic finished
    [ESPLED.sch, _saved_ESPLED.sch]
2019-01-15 schematic pdf added
2019-01-16 gerber addedededed
    [ESPLED-B.Cu.gbr, ESPLED-B.Mask.gbr, ESPLED-B.SilkS.gbr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]
2019-01-17 final 01:11
    [ESPLED.kicad_pcb]
2019-01-17 gerber final
    [ESPLED-B.Cu.gbl, ESPLED-B.Cu.gbr, ESPLED-B.Mask.gbr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]
2019-03-04 rearranges structure
    [ESPLED-2018-11-27-00-14-09.sch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]
2019-03-04 added pwm submodule
2019-05-28 Bitte sei wieder der MASTER
2019-11-06 Changed README.md to get back on track
2019-11-07 Added BOM
    [ESPLED.csv, bom.csv]
2019-11-07 removed tmp files
    [bom.csv]
2020-04-14 Edit README and experimental pwm library
2020-04-14 Move typedefs to seperate header file (and fix missing semicolon)
    [main.cpp]
2020-04-15 add footprint of handler function
2020-04-15 for fixing board :*?
    [main.cpp]
2020-04-16 Switch to OTA Updates
2020-04-16 Replace Serial with Debug functon
    [main.cpp]
2020-04-16 Fix ADC read
2020-04-16 Shorten debug message on new mqtt messages
    [main.cpp]
2020-04-16 move debugFkt so it only prints something during the fade
2020-04-17 Fix Pin Definiton Swap (CW WW)
2020-04-17 Fix MQTT message scrambling (Debug function interferred)
    [main.cpp]
2020-04-17 Add breathe mode prototype
2020-04-17 Fix yet another CW WW swap
    [main.cpp]
2020-04-17 Remove unnecessary includes and fix IP print
    [main.cpp]
2020-04-18 Add missing dependency: arduinoFFT Change upload port to OTA test device
2020-04-19 fixxed ip adress displaying in initWifi
    [main.cpp]
2020-04-19 Introduce advanced debug features(cycle count, free heap) and configurable pwmFrequency
2020-04-28 resolve #22 - initMQTT now publishes a message under the /ESPLED/ on each mqtt connect
    [main.cpp]
2020-04-28 Reconnect MQTT + reenable debug. Fix #6
    [main.cpp]
2020-04-28 Change Capacitor size, fix #23 move C4 near ESP8266, fix #11 change label P1 to P3, fix #12
    [ESPLED.kicad_pcb, ESPLED.sch]
2020-04-28 current status dome
2020-04-28 Add Backup of pcb
2020-05-02 Remove MQTT topic generation from initWifi + timing fix in initMQTT
    [main.cpp]
2020-05-02 Remove unused PWM Library
2020-05-02 split main.cpp in multiple files
    [configuration.h]
2020-05-07 implement blink mode + persistent var silo
    [configuration.h]
2020-10-19 Remove debug message in wrong topic
    [initFunctions.h]
2020-10-23 Fix Compiler Warning because no return is made in default case
2020-10-25 Add var strip_length into which we save the wifimanager parameter strip_length
    [configuration.h]
2020-10-25 handle -1 standard value and process error state
    [initFunctions.h]
2020-10-25 kind of working, crashes, oldColor must be handled
    [initFunctions.h, main.cpp]
2020-10-26 Add Variable for RGB order
    [configuration.h]
2020-10-26 doch nich
    [configuration.h]
2020-10-26 Add default case for bus initialization and add debug messages
2020-10-29 printVector working without arguments
2020-10-29 Use cycle count instead of millis() for time measurement. Reduce samples
